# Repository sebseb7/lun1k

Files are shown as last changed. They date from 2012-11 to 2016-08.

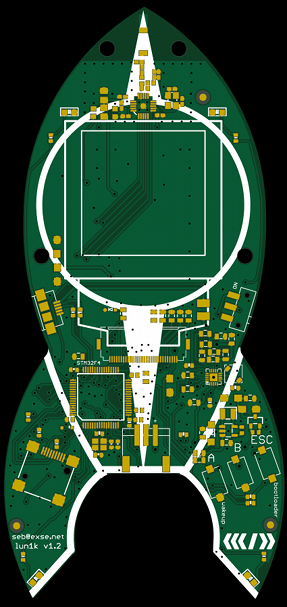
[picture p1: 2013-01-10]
sim/lun1k.png

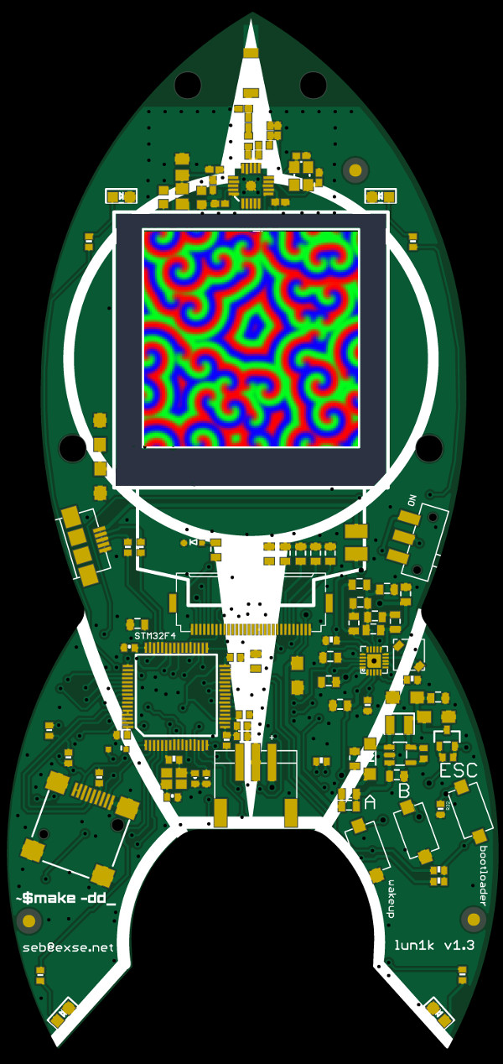
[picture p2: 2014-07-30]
eagle/lun1k.jpg

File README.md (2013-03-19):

endorse (http://coderwall.com/sebseb7)

lun1k
=====

find a toolchain here: https://launchpad.net/gcc-arm-embedded

eagle

endorse (http://coderwall.com/sebseb7)

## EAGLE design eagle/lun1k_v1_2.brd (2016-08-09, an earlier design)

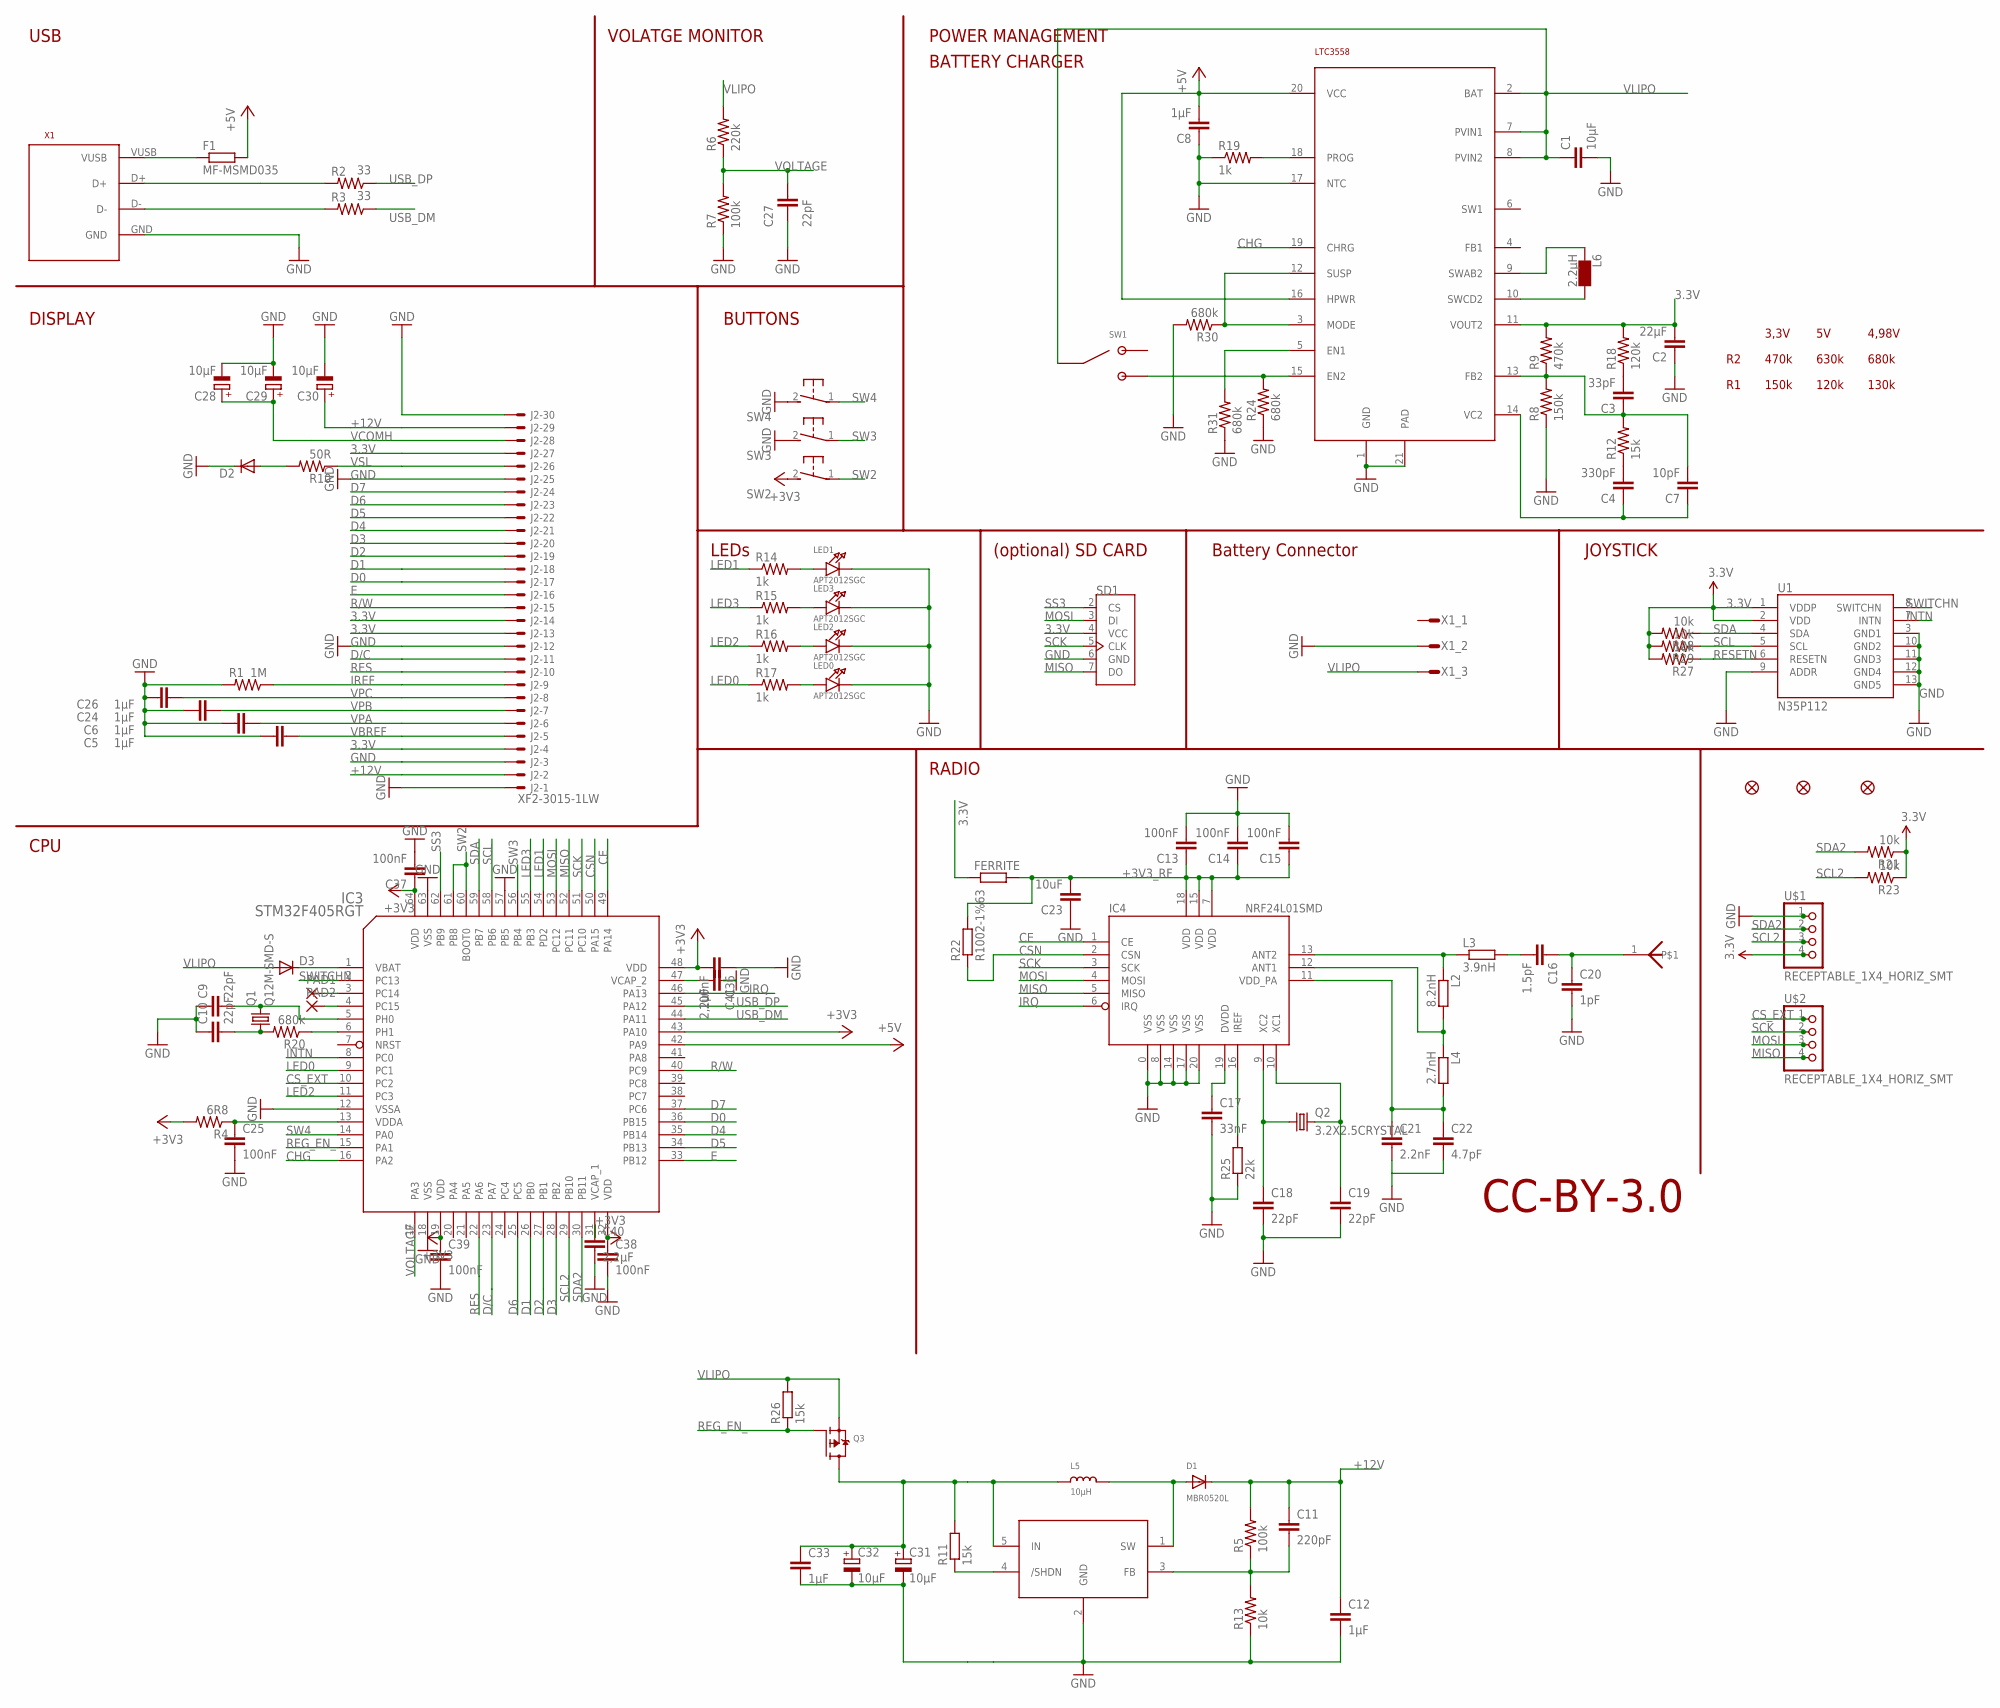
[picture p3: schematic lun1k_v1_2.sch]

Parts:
ANT: CHIPANTENNA
C1: 10µF; 0805
C2: 22µF; 0805
C3: 33pF; 0805
C4: 330pF; 0805
C5, C6, C8, C12, C24, C26, C33: 1µF; 0805
C7: 10pF; 0805
C9, C10, C27: 22pF; 0402-CAP
C11: 220pF; 0805
C13, C14, C15: 100nF; C0402K
C16: 1.5pF; C0402K
C17: 33nF; C0402K
C18, C19: 22pF; C0402K
C20: 1pF; C0402K
C21: 2.2nF; C0402K
C22: 4.7pF; C0402K
C23: 10uF; C0805K
C25, C36, C37, C38, C39: 100nF; 0402-CAP
C28, C29, C30, C31, C32: 10µF; SMC_A
C40, C41: 2,2µF; 0805
D1: MBR0520L; SOD-123
D2, D3: DIODE-SOD323-R; SOD323-R
F1: MF-MSMD035; R1210
FERRITE: R-EU_R0805; R0805
FID1, FID2, FID3: FIDUCIAL1.5X3; FIDUCIAL-1.5X3
IC1: LTC3558; UD-QFN20
IC2: LM27313; SOT23-5L
IC3: STM32F405RGT; LQFP64
IC4: NRF24L01SMD; QFN20
J2: XF2-3015-1LW; XF2H-3015-1LW
L2: 8.2nH; R0402
L3: 3.9nH; R0402
L4: 2.7nH; R0402
L5: 10µH; INDUCTOR_1007
L6: 2.2µH; CDRH3D16
LED0, LED1, LED2, LED3: APT2012SGC; CHIPLED_0805
PAD1, PAD2: SMD2; SMD1,27-2,54
Q1: Q12M-SMD-S; X22
Q2: 3.2X2.5CRYSTAL; CRYSTAL3.2X2.5
Q3: MOSFET-P; SOT23-R
R1: 1M; 0805
R2, R3: 33; 0402-RES
R4: 6R8; 0402-RES
R5: 100k; 0805
R6: 220k; 0402-RES
R7: 100k; 0402-RES
R8: 150k; 0805
R9: 470k; 0805
R10: 50R; 0805
R11, R26: 15k; R0402
R12: 15k; 0805
R13: 10k; 0805
R14, R15, R16, R17: 1k; 0402-RES
R18: 120k; 0805
R19: 1k; 0805
R20, R24, R30, R31: 680k; 0402-RES
R21, R23, R27, R28, R29: 10k; 0402-RES
R22: R1002-1%63; R0603
R25: 22k; R0603
SD1: MICROSD_SF-MICROSD; MICROSD_MICROSD
SW1: JS102011SAQN
SW2, SW3, SW4: SWITCH_MCTAEF
U1: N35P112
U$1, U$2: RECEPTABLE_1X4_HORIZ_SMT
X1: MICROUSB; MICROAB
X1_: JST-PH3

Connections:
3.3V: C2.2, C36.2, C37.1, C38.1, C39.1, FERRITE.1, IC1.11 (VOUT2), IC3.19 (VDD), IC3.32 (VDD), IC3.43 (PA10), IC3.48 (VDD), IC3.64 (VDD), J2.4 (MS), J2.13 (MS), J2.14 (MS), J2.27 (MS), R4.2, R9.2, R18.2, R21.1, R23.1, R27.2, R28.2, R29.2, SD1.4 (VCC), SW2.2, U1.1 (VDDP), U1.2 (VDD), U$1.4, U$1.4@1 (4)
+3V3_RF: C13.1, C14.1, C15.1, C23.2, FERRITE.2, IC4.7 (VDD), IC4.15 (VDD), IC4.18 (VDD), R22.2
+5V: C8.2, F1.2, IC1.16 (HPWR), IC1.20 (VCC), IC3.42 (PA9)
+12V: C11.1, C12.1, C30.+, D1.C, J2.2 (MS), J2.29 (MS), R5.2
CE: IC3.49 (PA14), IC4.1 (CE)
CHG: IC1.19 (CHRG), IC3.16 (PA2)
CSN: IC3.50 (PA15), IC4.2 (CSN), R22.1
CS_EXT: IC3.10 (PC2), U$2.1, U$2.1@1 (1)
D0: IC3.36 (PB15), J2.17 (MS)
D1: IC3.26 (PB0), J2.18 (MS)
D2: IC3.27 (PB1), J2.19 (MS)
D3: IC3.28 (PB2), J2.20 (MS)
D4: IC3.35 (PB14), J2.21 (MS)
D5: IC3.34 (PB13), J2.22 (MS)
D6: IC3.25 (PC5), J2.23 (MS)
D7: IC3.37 (PC6), J2.24 (MS)
D+: R2.2, X1.D+
D-: R3.2, X1.D-
D/C: IC3.23 (PA7), J2.11 (MS)
E: IC3.33 (PB12), J2.16 (MS)
EN2: IC1.15 (EN2), R24.2, SW1.3
GND: C1.2, C2.1, C5.1, C6.1, C8.1, C9.1, C10.1, C12.2, C13.2, C14.2, C15.2, C17.2, C18.2, C19.2, C20.2, C21.2, C22.2, C23.1, C24.1, C25.2, C26.1, C27.1, C28.-, C29.-, C30.-, C31.-, C32.-, C33.2, C36.1, C37.2, C38.2, C39.2, C40.2, C41.1, D2.C, IC1.1 (GND), IC1.17 (NTC), IC1.21 (PAD), IC2.2 (GND), IC3.12 (VSSA), IC3.18 (VSS), IC3.57 (PB5), IC3.63 (VSS), IC4.0 (VSS), IC4.8 (VSS), IC4.14 (VSS), IC4.17 (VSS), IC4.20 (VSS), J2.1 (MSV), J2.3 (MS), J2.12 (MS), J2.25 (MS), J2.30 (MS), LED0.C, LED1.C, LED2.C, LED3.C, R1.2, R7.1, R8.1, R13.1, R19.1, R24.1, R25.1, R30.2, R31.1, SD1.6 (GND), SW3.2, SW4.2, U1.3 (GND1), U1.9 (ADDR), U1.10 (GND2), U1.11 (GND3), U1.12 (GND4), U1.13 (GND5), U$1.1, U$1.1@1 (1), X1.GND, X1_.2
INTN: IC3.8 (PC0), U1.7 (INTN)
IREF: J2.9 (MS), R1.1
IRQ: IC3.46 (PA13), IC4.6 (IRQ)
LED0: IC3.9 (PC1), R17.1
LED1: IC3.54 (PD2), R14.1
LED2: IC3.11 (PC3), R16.1
LED3: IC3.55 (PB3), R15.1
MISO: IC3.52 (PC11), IC4.5 (MISO), SD1.7 (DO), U$2.4, U$2.4@1 (4)
MOSI: IC3.53 (PC12), IC4.4 (MOSI), SD1.3 (DI), U$2.3, U$2.3@1 (3)
unnamed: C9.2, IC3.5 (PH0), Q1.3 (2)
unnamed: IC1.18 (PROG), R19.2
unnamed: C10.2, Q1.1, R20.2
unnamed: LED0.A, R17.2
unnamed: LED2.A, R16.2
unnamed: LED3.A, R15.2
unnamed: C3.1, C7.2, IC1.13 (FB2), R8.2, R9.1, R12.2
unnamed: F1.1, X1.VUSB
unnamed: LED1.A, R14.2
unnamed: C18.1, IC4.9 (XC2), Q2.1
unnamed: C19.1, IC4.10 (XC1), Q2.3 (2)
unnamed: ANT.1, C16.1, C20.1
unnamed: C3.2, R18.1
unnamed: D2.A, R10.2
unnamed: C25.1, IC3.13 (VDDA), R4.1
unnamed: C4.2, R12.1
unnamed: C4.1, C7.1, IC1.14 (VC2)
unnamed: IC1.10 (SWCD2), L6.P$1 (1)
unnamed: C40.1, IC3.31 (VCAP_1)
unnamed: C41.2, IC3.47 (VCAP_2)
unnamed: IC3.3 (PC14), PAD1.1
unnamed: IC1.9 (SWAB2), L6.P$2 (2)
unnamed: IC3.4 (PC15), PAD2.1
unnamed: D1.A, IC2.1 (SW), L5.P$2 (2)
unnamed: IC1.3 (MODE), IC1.12 (SUSP), R30.1
unnamed: C11.2, IC2.3 (FB), R5.1, R13.2
unnamed: IC1.5 (EN1), R31.2
unnamed: IC3.6 (PH1), R20.1
unnamed: D3.C, IC3.1 (VBAT)
unnamed: IC2.4 (/SHDN), R11.1
unnamed: C17.1, IC4.19 (DVDD)
unnamed: IC4.16 (IREF), R25.2
unnamed: C21.1, C22.1, IC4.11 (VDD_PA), L4.2
unnamed: IC4.12 (ANT1), L2.2, L4.1
unnamed: IC4.13 (ANT2), L2.1, L3.1
unnamed: C16.2, L3.2
R/W: IC3.40 (PC9), J2.15 (MS)
REG_EN_: IC3.15 (PA1), Q3.1 (G), R26.1
RES: IC3.22 (PA6), J2.10 (MS)
RESETN: R27.1, U1.6 (RESETN)
SCK: IC3.51 (PC10), IC4.3 (SCK), SD1.5 (CLK), U$2.2, U$2.2@1 (2)
SCL: IC3.58 (PB6), R29.1, U1.5 (SCL)
SCL2: IC3.29 (PB10), R23.2, U$1.3, U$1.3@1 (3)
SDA: IC3.59 (PB7), R28.1, U1.4 (SDA)
SDA2: IC3.30 (PB11), R21.2, U$1.2, U$1.2@1 (2)
SS3: IC3.62 (PB9), SD1.2 (CS)
SW2: IC3.60 (BOOT0), IC3.61 (PB8), SW2.1
SW3: IC3.56 (PB4), SW3.1
SW4: IC3.14 (PA0), SW4.1
SWITCHN: IC3.2 (PC13), U1.8 (SWITCHN)
USB_DM: IC3.44 (PA11), R3.1
USB_DP: IC3.45 (PA12), R2.1
VBREF: C5.2, J2.5 (MS)
VCOMH: C28.+, C29.+, J2.28 (MS)
VLIPO: C1.1, D3.A, IC1.2 (BAT), IC1.7 (PVIN1), IC1.8 (PVIN2), Q3.2 (S), R6.2, R26.2, SW1.2, X1_.3
VOLTAGE: C27.2, IC3.17 (PA3), R6.1, R7.2
VPA: C6.2, J2.6 (MS)
VPB: C24.2, J2.7 (MS)
VPC: C26.2, J2.8 (MS)
VREGIN: C31.+, C32.+, C33.1, IC2.5 (IN), L5.P$1 (1), Q3.3 (D), R11.2
VSL: J2.26 (MS), R10.1

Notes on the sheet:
POWER MANAGEMENT
DISPLAY
USB
BATTERY CHARGER
VOLATGE MONITOR
LEDs
(optional) SD CARD
JOYSTICK
CPU
RADIO
CC-BY-3.0
BUTTONS
3,3V
4,98V
470k
150k
630k
120k
680k
130k
Battery Connector

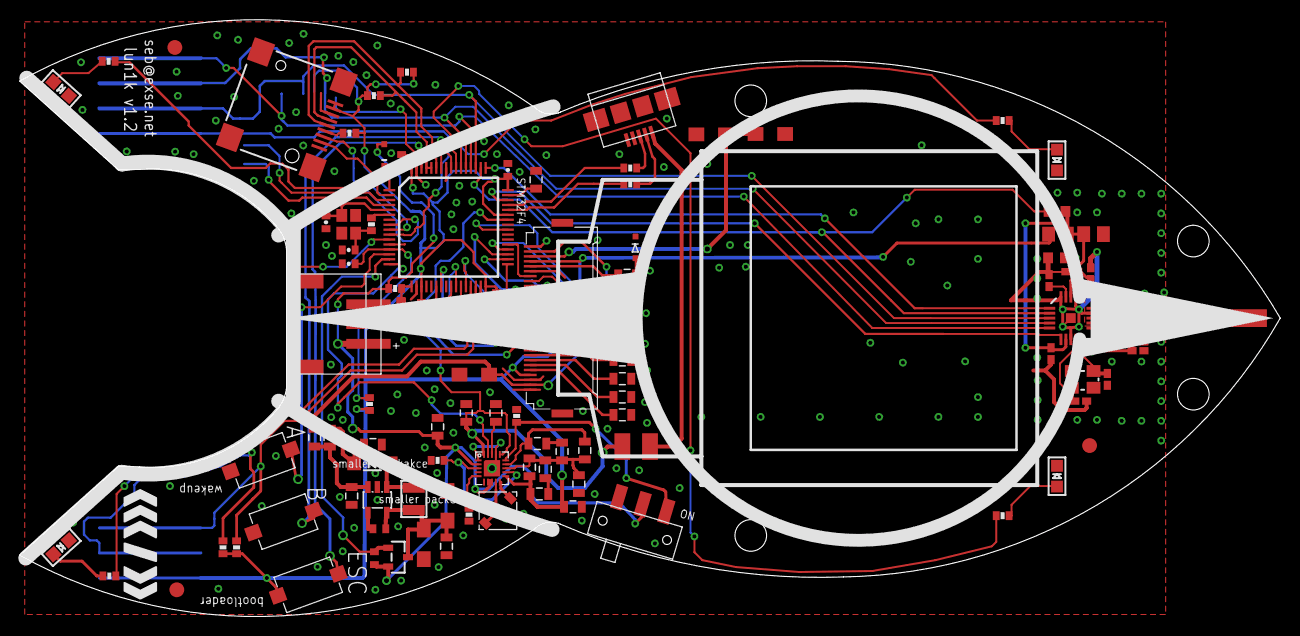
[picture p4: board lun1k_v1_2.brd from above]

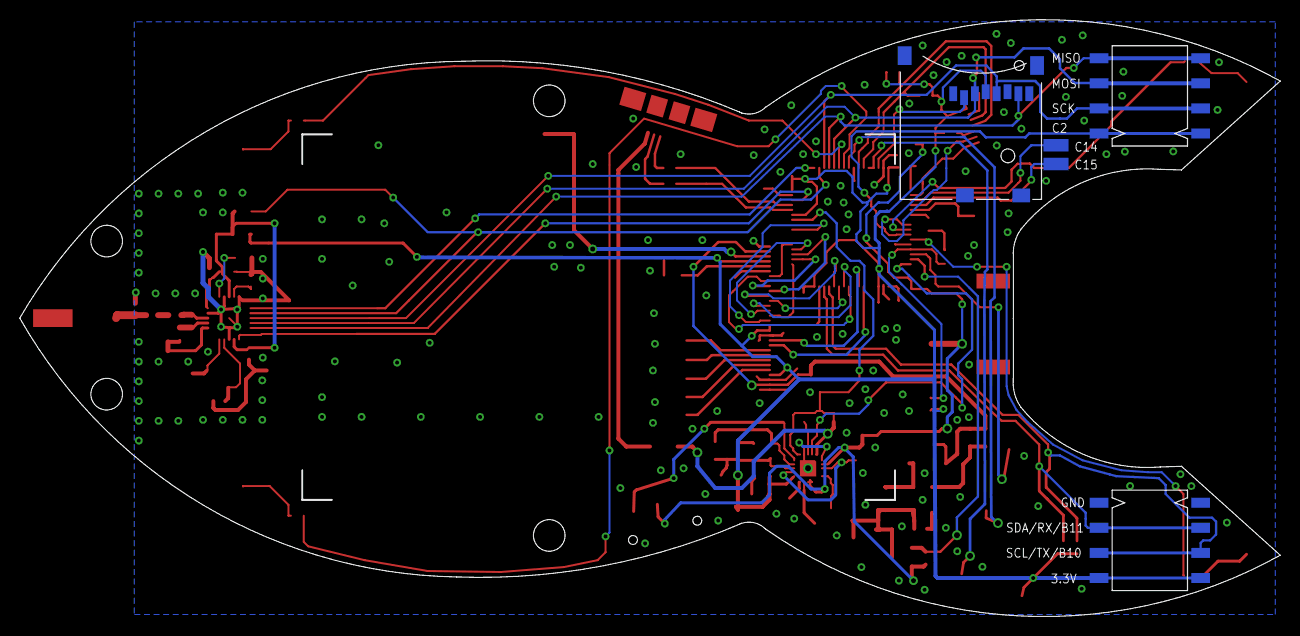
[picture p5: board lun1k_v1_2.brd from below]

Board: 2 copper layers, 127.6 x 60.4 mm, 108 parts (5 on the bottom side), 92 nets.

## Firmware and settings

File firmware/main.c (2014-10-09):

#include <stdlib.h>

#include "main.h"
#include "libs/mcugui/circle.h"
#include "arm_math.h" 
#include "n35p112.h"
#include "rng.h"
#include "libs/mcugui/text.h"
#include "adc.h"


//#include "lib/usb_serial.h"

/*
 *	boot loader: http://www.st.com/stonline/stappl/st/com/TECHNICAL_RESOURCES/TECHNICAL_LITERATURE/APPLICATION_NOTE/CD00167594.pdf (page 31)
 *	datasheet: http://www.st.com/internet/com/TECHNICAL_RESOURCES/TECHNICAL_LITERATURE/DATASHEET/DM00037051.pdf
 *	user manual: http://www.st.com/internet/com/TECHNICAL_RESOURCES/TECHNICAL_LITERATURE/REFERENCE_MANUAL/DM00031020.pdf
 */

static __IO uint32_t TimingDelay;
static __IO uint32_t tick;
void Delay(__IO uint32_t nTime)
{
	TimingDelay = nTime*10;

	while(TimingDelay != 0);
}
static void Delay100us(__IO int32_t nTime)
{

	if(nTime > 0)
	{

		TimingDelay = nTime;

		while(TimingDelay != 0);
	}
}



static uint16_t key_state;
static uint16_t key_press;
uint32_t buttonsInitialized = 0;


void TimingDelay_Decrement(void)
{
	static uint16_t ct0, ct1;
	static uint8_t button_sample = 0;
	uint16_t i;


	if (TimingDelay != 0x00)
	{ 
		TimingDelay--;
	}
	tick++;
	if(buttonsInitialized)
	{
		button_sample++;
		if(button_sample < 100)
			return;

		button_sample = 0;

		uint16_t key_curr = ((GPIO_ReadInputDataBit(GPIOB, GPIO_Pin_8)^1)<<1)|
							(GPIO_ReadInputDataBit(GPIOC, GPIO_Pin_13)<<2)|
							(GPIO_ReadInputDataBit(GPIOB, GPIO_Pin_4)<<3)|
							GPIO_ReadInputDataBit(GPIOA, GPIO_Pin_0);

		i = key_state ^ ~key_curr;
		ct0 = ~( ct0 & i );
		ct1 = ct0 ^ (ct1 & i);
		i &= ct0 & ct1;
		key_state ^= i;
		key_press |= key_state & i;
	}
}
uint32_t getSysTick(void)
{
	return tick;
}
uint16_t get_key_press( uint16_t key_mask )
{
	key_mask &= key_press;                          // read key(s)
	key_press ^= key_mask;                          // clear key(s)
	return key_mask;
}

uint16_t get_key_state( uint16_t key_mask )
{
	return key_mask & key_press;
}

static uint32_t i2c_e[7] = {0,0,0,0,0,0,0};

void i2c_error(uint8_t error)
{
	i2c_e[error-1]++;
}


#define MAX_ANIMATIONS 30

static int animationcount;



struct animation {
	char* name;
	init_fun init_fp;
	tick_fun tick_fp;
	deinit_fun deinit_fp;
	uint16_t duration;
	int16_t timing;
};

static struct animation animations[MAX_ANIMATIONS] ;

static uint8_t joy_x=0;
static 	uint8_t joy_y=0;

void get_stick(uint8_t *x,uint8_t *y)
{
	*x = joy_x;
	*y = joy_y;
}

void registerAnimation(char* name,init_fun init,tick_fun tick, deinit_fun deinit,uint16_t t, uint16_t count)
{

	// this is for initialization, probably registerAnimation gets called bevore global variables are initialized
	static int firstrun = 1;

	if(firstrun == 1)
	{
		firstrun = 0;
		animationcount = 0;
	}


	if(animationcount == MAX_ANIMATIONS)
		return;
	animations[animationcount].init_fp = init;
	animations[animationcount].tick_fp = tick;
	animations[animationcount].deinit_fp = deinit;
	animations[animationcount].duration = count;
	animations[animationcount].timing = t;
	animations[animationcount].name = name;

	animationcount++;
}


int main(void)
{
	RCC_ClocksTypeDef RCC_Clocks;


	RCC_GetClocksFreq(&RCC_Clocks);
	/* SysTick end of count event each 0.1ms */
	SysTick_Config(RCC_Clocks.HCLK_Frequency / 10000);

	RCC_AHB1PeriphClockCmd(RCC_AHB1Periph_GPIOA, ENABLE);
	RCC_AHB1PeriphClockCmd(RCC_AHB1Periph_GPIOB, ENABLE);
	RCC_AHB1PeriphClockCmd(RCC_AHB1Periph_GPIOC, ENABLE);
	RCC_AHB1PeriphClockCmd(RCC_AHB1Periph_GPIOD, ENABLE);
	
	
	//prepare init structure
	GPIO_InitTypeDef GPIO_InitStructure;
	GPIO_InitStructure.GPIO_Speed = GPIO_Speed_100MHz;
	GPIO_InitStructure.GPIO_Mode  = GPIO_Mode_OUT;
	GPIO_InitStructure.GPIO_OType = GPIO_OType_PP;
	GPIO_InitStructure.GPIO_PuPd = GPIO_PuPd_NOPULL;
/*
 *      10   11   12
 *
 * E    C7   C5   B12
 * DC   A7   A7   A7
 * RW   C9   C9   C9
 * RST  A6   A6   A6
 * D0   C4   B15  B15
 * D1   C5   B0   B0
 * D2   B0   B1   B1
 * D3   B1   B2   B2
 * D4   B15  B14  B14
 * D5   B14  B13  B13
 * D6   B13  B12  C5
 * D7   B12  C6   C6
 *
 * v11 : E,D0..D7 swapped
 * v12 : E and D6 swapped
 *
 */

	
	GPIO_InitStructure.GPIO_Pin   = GPIO_Pin_6;
	GPIO_Init(GPIOA, &GPIO_InitStructure);
	GPIO_InitStructure.GPIO_Pin   = GPIO_Pin_7;
	GPIO_Init(GPIOA, &GPIO_InitStructure);
	GPIO_InitStructure.GPIO_Pin   = GPIO_Pin_0;
	GPIO_Init(GPIOB, &GPIO_InitStructure);
	GPIO_InitStructure.GPIO_Pin   = GPIO_Pin_1;
	GPIO_Init(GPIOB, &GPIO_InitStructure);
#if LUN1K_VERSION >= 11
	GPIO_InitStructure.GPIO_Pin   = GPIO_Pin_2;
	GPIO_Init(GPIOB, &GPIO_InitStructure);
#endif
	GPIO_InitStructure.GPIO_Pin   = GPIO_Pin_12;
	GPIO_Init(GPIOB, &GPIO_InitStructure);
	GPIO_InitStructure.GPIO_Pin   = GPIO_Pin_13;
	GPIO_Init(GPIOB, &GPIO_InitStructure);
	GPIO_InitStructure.GPIO_Pin   = GPIO_Pin_14;
	GPIO_Init(GPIOB, &GPIO_InitStructure);
	GPIO_InitStructure.GPIO_Pin   = GPIO_Pin_15;
	GPIO_Init(GPIOB, &GPIO_InitStructure);
#if LUN1K_VERSION == 10
	GPIO_InitStructure.GPIO_Pin   = GPIO_Pin_4;
	GPIO_Init(GPIOC, &GPIO_InitStructure);
#endif
	GPIO_InitStructure.GPIO_Pin   = GPIO_Pin_5;
	GPIO_Init(GPIOC, &GPIO_InitStructure);
#if LUN1K_VERSION >= 11
	GPIO_InitStructure.GPIO_Pin   = GPIO_Pin_6;
	GPIO_Init(GPIOC, &GPIO_InitStructure);
#endif
#if LUN1K_VERSION == 10
	GPIO_InitStructure.GPIO_Pin   = GPIO_Pin_7;
	GPIO_Init(GPIOC, &GPIO_InitStructure);
#endif
	GPIO_InitStructure.GPIO_Pin   = GPIO_Pin_9;
	GPIO_Init(GPIOC, &GPIO_InitStructure);

	//leds
	GPIO_InitStructure.GPIO_Pin   = GPIO_Pin_2;       
	GPIO_Init(GPIOD, &GPIO_InitStructure);  
	GPIO_InitStructure.GPIO_Pin   = GPIO_Pin_1;       
	GPIO_Init(GPIOC, &GPIO_InitStructure);  
	GPIO_InitStructure.GPIO_Pin   = GPIO_Pin_3;       
	GPIO_Init(GPIOC, &GPIO_InitStructure);  
	GPIO_InitStructure.GPIO_Pin   = GPIO_Pin_3;       
	GPIO_Init(GPIOB, &GPIO_InitStructure);  

	//regen
	GPIO_InitStructure.GPIO_Pin   = GPIO_Pin_1;       
	GPIO_Init(GPIOA, &GPIO_InitStructure);  


	//ESC Button
	GPIO_InitStructure.GPIO_Mode  = GPIO_Mode_IN;
	GPIO_InitStructure.GPIO_PuPd = GPIO_PuPd_DOWN;
	GPIO_InitStructure.GPIO_Pin   = GPIO_Pin_8;       
	GPIO_Init(GPIOB, &GPIO_InitStructure);  
	
	//stick button
	GPIO_InitStructure.GPIO_PuPd = GPIO_PuPd_UP;
	GPIO_InitStructure.GPIO_Pin   = GPIO_Pin_13;       
	GPIO_Init(GPIOC, &GPIO_InitStructure);  
	//A
	GPIO_InitStructure.GPIO_Pin   = GPIO_Pin_4;       
	GPIO_Init(GPIOB, &GPIO_InitStructure);  
	//B
	GPIO_InitStructure.GPIO_Pin   = GPIO_Pin_0;       
	GPIO_Init(GPIOA, &GPIO_InitStructure);  
	buttonsInitialized=1;
		


	//set RW to 0
	GPIO_ResetBits(GPIOC,GPIO_Pin_9);	

	// 12V power
	GPIOA->ODR           |=       1<<1;


	RNG_Enable();
	srand(RNG_Get());
	RNG_Disable();

	adc_a3_init();

	lcdInit();
	
	n35p112_init();

	
	int current_animation = 0;
	animations[current_animation].init_fp();
	int tick_count = 0;
	

	int loopcount = 0;

	uint8_t count  = 0;
		
	int16_t bat_voltage = adc_a3_get();

	float voltagesample = bat_voltage;

	while(1)
	{
		loopcount++;
		if((loopcount == 55)||(loopcount == 57))
		{
			GPIOC->ODR           |=       1<<1;
			GPIOD->ODR           |=       1<<2;
			GPIOB->ODR           |=       1<<3;
			GPIOC->ODR           |=       1<<3;
		}
		if((loopcount == 56)||(loopcount == 58))
		{
			GPIOC->ODR           &=       ~(1<<1);
			GPIOD->ODR           &=       ~(1<<2);
			GPIOB->ODR           &=       ~(1<<3);
			GPIOC->ODR           &=       ~(1<<3);
			if(loopcount==58)
				loopcount = 0;
		}
		
		uint32_t start_tick = tick;

		get_n35p112(&joy_x,&joy_y);

		animations[current_animation].tick_fp();
/*		int16_t bat_voltage = adc_a3_get();

		fill_8x6(20,20, 5,0,0,0);
		fill_8x6(20,30, 5,0,0,0);
		draw_number_8x6(20,20, bat_voltage, 5, ' ' ,255,255,255);

		voltagesample = voltagesample * 0.98f;
		voltagesample += bat_voltage * 0.02f;


		float tmp2 = voltagesample / (4096.0f / 3.3f);

		float tmp3 = tmp2 * 2.14f;

		draw_number_8x6(20,30, tmp3*1000, 5, ' ' ,255,255,255);

		setLedXY(bat_voltage-2364, count,255,0,0);*/

		lcdFlush();

		uint32_t duration = tick - start_tick;

		//draw_number_8x6(20,20, animations[current_animation].timing - duration, 6, ' ' ,255,255,255);


		if(animations[current_animation].timing > 0)
			Delay100us(animations[current_animation].timing - duration);
	

//		draw_number_8x6(20,30, joy_y, 3, ' ' ,255,255,255);

//		draw_filledCircle(joy_y>>1,joy_x>>1,8,0,0,0);
//		draw_filledCircle(joy_y>>1,joy_x>>1,5,255,255,255);


		count++;
		if(count > 128)
			count=0;

		tick_count++;


		if(get_key_press(KEY_ESC))
		{
			animations[current_animation].deinit_fp();

			current_animation++;
			if(current_animation == animationcount)
			{
				current_animation = 0;
			}
			tick_count=0;
	
			lcdFillRGB(0,0,0);

			animations[current_animation].init_fp();

			//usb_printf("diff: %i , %i (%i) (%i %i %i %i %i %i %i)\n",diff,int_status,i2c_errors,i2c_e[0],i2c_e[1],i2c_e[2],i2c_e[3],i2c_e[4],i2c_e[5],i2c_e[6]);

		}
	}

}

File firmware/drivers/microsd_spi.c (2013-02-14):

/*-----------------------------------------------------------------------*/
/* MMC/SDSC/SDHC (in SPI mode) control module for STM32 Version 1.1.6    */
/* (C) Martin Thomas, 2010 - based on the AVR MMC module (C)ChaN, 2007   */
/*-----------------------------------------------------------------------*/

/* Copyright (c) 2010, Martin Thomas, ChaN
   All rights reserved.

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
  THIS SOFTWARE IS PROVIDED BY THE COPYRIGHT HOLDERS AND CONTRIBUTORS "AS IS"
  AND ANY EXPRESS OR IMPLIED WARRANTIES, INCLUDING, BUT NOT LIMITED TO, THE
  IMPLIED WARRANTIES OF MERCHANTABILITY AND FITNESS FOR A PARTICULAR PURPOSE
  ARE DISCLAIMED. IN NO EVENT SHALL THE COPYRIGHT OWNER OR CONTRIBUTORS BE
  LIABLE FOR ANY DIRECT, INDIRECT, INCIDENTAL, SPECIAL, EXEMPLARY, OR
  CONSEQUENTIAL DAMAGES (INCLUDING, BUT NOT LIMITED TO, PROCUREMENT OF
  SUBSTITUTE GOODS OR SERVICES; LOSS OF USE, DATA, OR PROFITS; OR BUSINESS
  INTERRUPTION) HOWEVER CAUSED AND ON ANY THEORY OF LIABILITY, WHETHER IN
  CONTRACT, STRICT LIABILITY, OR TORT (INCLUDING NEGLIGENCE OR OTHERWISE)
  ARISING IN ANY WAY OUT OF THE USE OF THIS SOFTWARE, EVEN IF ADVISED OF THE
  POSSIBILITY OF SUCH DAMAGE. */


#if STM32F == 1
#include "stm32f10x.h"
#endif
#if STM32F == 2
#include "stm32f2xx.h"
#endif
#if STM32F == 4
#include "stm32f4xx.h"
#endif
#include "ffconf.h"
#include "diskio.h"
#include "main.h"

// demo uses a command line option to define this (see Makefile):
// #define STM32_SD_USE_DMA


#ifdef STM32_SD_USE_DMA
// #warning "Information only: using DMA"
#pragma message "*** Using DMA ***"
#endif


// MOSI C12
// SCK C10
// CS A15
// MISO B4


/* set to 1 to provide a disk_ioctrl function even if not needed by the FatFs */
#define STM32_SD_DISK_IOCTRL_FORCE      0

#define CARD_SUPPLY_SWITCHABLE   0
#define SOCKET_WP_CONNECTED      0
#define SPIx_SD                         SPI3
#define SPIx_SD_CLK                     RCC_APB1Periph_SPI3
#define SPIx_SD_CLK_INIT                RCC_APB1PeriphClockCmd
#define SPIx_SD_IRQn                    SPI3_IRQn
#define SPIx_SD_IRQHANDLER              SPI3_IRQHandler

#define SPIx_SD_SCK_PIN                 GPIO_Pin_10
#define SPIx_SD_SCK_GPIO_PORT           GPIOC
#define SPIx_SD_SCK_GPIO_CLK            RCC_AHB1Periph_GPIOC
#define SPIx_SD_SCK_SOURCE              GPIO_PinSource10
#define SPIx_SD_SCK_AF                  GPIO_AF_SPI3

#define SPIx_SD_MISO_PIN                GPIO_Pin_11
#define SPIx_SD_MISO_GPIO_PORT          GPIOC
#define SPIx_SD_MISO_GPIO_CLK           RCC_AHB1Periph_GPIOC
#define SPIx_SD_MISO_SOURCE             GPIO_PinSource11
#define SPIx_SD_MISO_AF                 GPIO_AF_SPI3

#define SPIx_SD_MOSI_PIN                GPIO_Pin_12
#define SPIx_SD_MOSI_GPIO_PORT          GPIOC
#define SPIx_SD_MOSI_GPIO_CLK           RCC_AHB1Periph_GPIOC
#define SPIx_SD_MOSI_SOURCE             GPIO_PinSource12
#define SPIx_SD_MOSI_AF                 GPIO_AF_SPI3

#define SPIx_SD_NSS_PIN                	GPIO_Pin_9
#define SPIx_SD_NSS_GPIO_PORT          	GPIOB
#define SPIx_SD_NSS_GPIO_CLK           	RCC_AHB1Periph_GPIOB
#define SPIx_SD_NSS_SOURCE             	GPIO_PinSource9

#define SPIx_SD_BAUDRATE_SLOW  			SPI_BaudRatePrescaler_128
#define SPIx_SD_BAUDRATE_FAST  			SPI_BaudRatePrescaler_8


/*#define SPI_SD                   SPI2
#define GPIO_CS                  GPIOC
#define RCC_APB2Periph_GPIO_CS   RCC_AHB1Periph_GPIOB
#define GPIO_Pin_CS              GPIO_Pin_7
#define DMA_Channel_SPI_SD_RX    DMA1_Channel2
#define DMA_Channel_SPI_SD_TX    DMA1_Channel3
#define DMA_FLAG_SPI_SD_TC_RX    DMA1_FLAG_TC2
#define DMA_FLAG_SPI_SD_TC_TX    DMA1_FLAG_TC3
#define GPIO_SPI_SD              GPIOB
#define GPIO_Pin_SPI_SD_SCK      GPIO_Pin_10
#define GPIO_Pin_SPI_SD_MISO     GPIO_Pin_14
#define GPIO_Pin_SPI_SD_MOSI     GPIO_Pin_15
#define RCC_APBPeriphClockCmd_SPI_SD  RCC_APB1PeriphClockCmd
#define RCC_APBPeriph_SPI_SD     RCC_APB1Periph_SPI2
*/

/* - for SPI1 and full-speed APB2: 72MHz/4 */
#define SPI_BaudRatePrescaler_SPI_SD  SPI_BaudRatePrescaler_8


/* Definitions for MMC/SDC command */
#define CMD0	(0x40+0)	/* GO_IDLE_STATE */
#define CMD1	(0x40+1)	/* SEND_OP_COND (MMC) */
#define ACMD41	(0xC0+41)	/* SEND_OP_COND (SDC) */
#define CMD8	(0x40+8)	/* SEND_IF_COND */
#define CMD9	(0x40+9)	/* SEND_CSD */
#define CMD10	(0x40+10)	/* SEND_CID */
#define CMD12	(0x40+12)	/* STOP_TRANSMISSION */
#define ACMD13	(0xC0+13)	/* SD_STATUS (SDC) */
#define CMD16	(0x40+16)	/* SET_BLOCKLEN */
#define CMD17	(0x40+17)	/* READ_SINGLE_BLOCK */
#define CMD18	(0x40+18)	/* READ_MULTIPLE_BLOCK */
#define CMD23	(0x40+23)	/* SET_BLOCK_COUNT (MMC) */
#define ACMD23	(0xC0+23)	/* SET_WR_BLK_ERASE_COUNT (SDC) */
#define CMD24	(0x40+24)	/* WRITE_BLOCK */
#define CMD25	(0x40+25)	/* WRITE_MULTIPLE_BLOCK */
#define CMD55	(0x40+55)	/* APP_CMD */
#define CMD58	(0x40+58)	/* READ_OCR */

/* Card-Select Controls  (Platform dependent) */
#define SELECT()        GPIO_ResetBits(SPIx_SD_NSS_GPIO_PORT, SPIx_SD_NSS_PIN)    /* MMC CS = L */
#define DESELECT()      GPIO_SetBits(SPIx_SD_NSS_GPIO_PORT, SPIx_SD_NSS_PIN)      /* MMC CS = H */


#if (_MAX_SS != 512) || (_FS_READONLY == 0) || (STM32_SD_DISK_IOCTRL_FORCE == 1)
#define STM32_SD_DISK_IOCTRL   1
#else
#define STM32_SD_DISK_IOCTRL   0
#endif

/*--------------------------------------------------------------------------

   Module Private Functions and Variables

---------------------------------------------------------------------------*/

static volatile
DSTATUS Stat = STA_NOINIT;	/* Disk status */

static volatile
DWORD Timer1, Timer2;	/* 100Hz decrement timers */

static
BYTE CardType;			/* Card type flags */

enum speed_setting { INTERFACE_SLOW, INTERFACE_FAST };

static void interface_speed( enum speed_setting speed )
{
	DWORD tmp;

	tmp = SPIx_SD->CR1;
	if ( speed == INTERFACE_SLOW ) {
		/* Set slow clock (100k-400k) */
		tmp = ( tmp | SPI_BaudRatePrescaler_256 );
	} else {
		/* Set fast clock (depends on the CSD) */
		tmp = ( tmp & ~SPI_BaudRatePrescaler_256 ) | SPI_BaudRatePrescaler_SPI_SD;
	}
	SPIx_SD->CR1 = tmp;
}


/*-----------------------------------------------------------------------*/
/* Transmit/Receive a byte to MMC via SPI  (Platform dependent)          */
/*-----------------------------------------------------------------------*/
static BYTE stm32_spi_rw( BYTE out )
{
	/* Loop while DR register in not empty */
	/// not needed: while (SPI_I2S_GetFlagStatus(SPI_SD, SPI_I2S_FLAG_TXE) == RESET) { ; }

	/* Send byte through the SPI peripheral */
	SPI_I2S_SendData(SPIx_SD, out);

	/* Wait to receive a byte */
	while (SPI_I2S_GetFlagStatus(SPIx_SD, SPI_I2S_FLAG_RXNE) == RESET) { ; }

	/* Return the byte read from the SPI bus */
	return SPI_I2S_ReceiveData(SPIx_SD);
}



/*-----------------------------------------------------------------------*/
/* Transmit a byte to MMC via SPI  (Platform dependent)                  */
/*-----------------------------------------------------------------------*/

#define xmit_spi(dat)  stm32_spi_rw(dat)
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

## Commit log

2012-09-26 removed everything except r0ket_v2.sch r0ket_v2.brd and badge.lbr
    [m0dul-dual.brd, m0dul-dual.sch, m0dul-single.brd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]
2012-09-26 converted all eagle files to v6
    [r0ket_v2.brd, r0ket_v2.sch]
2012-09-26 removed a lot of components
    [r0ket_v2.brd, r0ket_v2.sch]
2012-09-26 renamed eagle files
    [lun1k.brd, lun1k.sch]
2012-09-27 added oled and 12v regulator
    [lun1k.brd, lun1k.sch]
2012-09-27 added farnell number for pfc connector
    [lun1k.sch]
2012-09-27 some wire cleanup
    [lun1k.brd]
2012-09-27 added cpu
    [lun1k.brd, lun1k.sch]
2012-09-27 fixed oled placement
    [lun1k.brd]
2012-09-27 placed components for the oled
    [lun1k.brd, lun1k.sch]
2012-09-27 placed mcu
    [lun1k.brd, lun1k.sch]
2012-09-27 replaced 0402 packages
    [lun1k.brd, lun1k.sch]
2012-09-27 smaller crystal
    [lun1k.brd, lun1k.sch]
2012-09-27 placed analog joystick
    [lun1k.brd, lun1k.sch]
2012-09-27 placed buttons
    [lun1k.brd, lun1k.sch]
2012-09-27 completely removed old supply & management
    [lun1k.brd, lun1k.sch]
2012-09-27 some resistors: 0603 -> 0402
    [lun1k.brd, lun1k.sch]
2012-09-27 new lipo charger
    [lun1k.brd, lun1k.sch]
2012-09-27 button text
    [lun1k.brd]
2012-09-27 current progress of the routing
2012-09-27 module connector
    [lun1k.sch]
2012-10-01 milestone 1
    [lun1k.brd]
2012-10-01 switch 12V supply part 1
    [lun1k.brd, lun1k.sch]
2012-10-01 switch 12V supply part 2
    [lun1k.brd, lun1k.sch]
2012-10-01 regulator final
    [lun1k.brd, lun1k.sch]
2012-10-05 unfinifhsed drivers
2012-11-01 minor changes
    [lun1k.brd, lun1k.sch]
2012-11-02 post production fixes
    [lun1k.brd, lun1k.sch]
2012-11-07 cleanup, fixed some compiler warnings, lun1k <-> simulator compatibility
    [main.c]
2012-11-07 printf now from libc
2012-11-08 sim: smarter FRAMETIME
2012-11-08 sim: fix font path on linux
    [main.c]
2012-11-08 cleanup and cunstructor support for stm32f2
2012-11-14 button support, smaller changes
2012-11-14 color and button stub
2012-11-14 added link to working stm32f4 toolchain
2012-11-17 debounce for all 4 buttons
2012-11-18 only stick key skips
    [main.c]
2012-11-21 removed printf
2012-12-04 fixes some warnings & malloc wrapper fix (still not working on linux)
    [main.c]
2012-12-05 fix no non linux
    [main.c]
2012-12-05 animations/notch: reduce memory footprint
    should malloc(81920) now
2012-12-05 animations/notch: use arm __VSQRTF
2012-12-05 animations/notch: don't use arm __VSQRTF
2012-12-13 animations/notch: now rendered in CD™!
    CD: Crappy Definition
2012-12-15 animations/bzr2: draw frametime
2012-12-15 animations/bzr2: micro-optimize with __QADD16/__QSUB16
    accounts for <5% less frametime
2012-12-19 removed dev board code
2012-12-19 removed dev-board code
2012-12-29 animations/bzr2: calc every frame, show FPS instead of frametime
2013-01-10 small fix
    [lun1k_v1_2.brd]
2013-01-31 device signature
2013-02-03 bootloader rubustness
    [lun1k_v1_3.brd, lun1k_v1_3.sch]
2013-02-15 groundwork for hal_file
2014-07-28 joxstick driver
2014-07-28 eeprom driver updates
2014-07-29 flash_db & adc & pcb misc
    [lun1k_v1_2.brd, lun1k_v1_3.brd, lun1k_v1_3.sch]
2014-07-30 v1.3 updates
    [lun1k_v1_3.brd, lun1k_v1_3.sch]
2014-07-30 joystick plasma disortion, fix simulator
    [main.c]

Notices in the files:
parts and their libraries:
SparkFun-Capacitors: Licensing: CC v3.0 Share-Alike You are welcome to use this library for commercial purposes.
